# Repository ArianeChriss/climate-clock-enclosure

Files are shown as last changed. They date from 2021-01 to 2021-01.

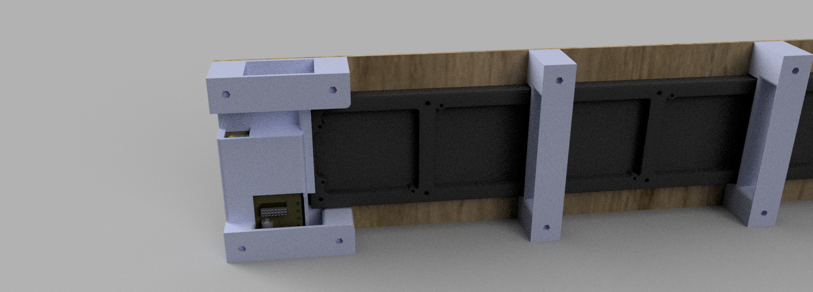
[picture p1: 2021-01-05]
three_panel_enclosure_v3 v19_back.png

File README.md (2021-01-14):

# climate-clock-enclosure
Enclosure design files for the portable versions of the climate clock at https://climateclock.world/make

# Notes:
**The .dxf files need to be updated with slightly smaller holes for the screws, and we're still in the process of testing the printed pieces with heat set inserts instead of nuts. Check back here for updates!!!**

# Materials:
24 M3x8 screws (I use socket cap screws)

24 M3 hex nuts **THIS WILL BE REPLACED WITH HEAT SET INSERTS AS SOON AS THEY ARE TESTED WITH THE DESIGN. AS OF RIGHT NOW, THE TENSION OF SCREWING IN THE WOOD WILL DETACH THE NUTS FROM THE 3D PRINT.**

3d printer filament

2 pieces of 1/8" material for laser cutting, minimum dimensions 27.75"x6" each

# Instructions:
1. Print all .stl files (part modeled in inches, if ridiculously small in print software scale by 2540%)
    center_1.stl
    center_2.stl
    case.stl
    end.stl
2. Laser cut all .dxf files (also designed in inches, dimensions should be 27.75” x 6”)
    front_cut.dxf
    back_cut.dxf
3. Use M3 hex nuts as heat-set inserts, set on top of holes in 3d printed parts, apply soldering iron (set to at least 315℉) and press gently to allow nut to settle into hole
    
    Instructions/description for using heat set inserts at https://markforged.com/resources/blog/heat-set-inserts
4. Center matrix displays on front laser cut piece
5. Place Raspberry Pi and HAT into case, use M3 x 8 screws to attach case, end and center pieces to front laser cut piece
6. May need to snip small plastic tabs off of display molding, depending on which displays are used
7. Attach all power and display cables
8. Use M3 x 8 screws to attach back laser cut piece

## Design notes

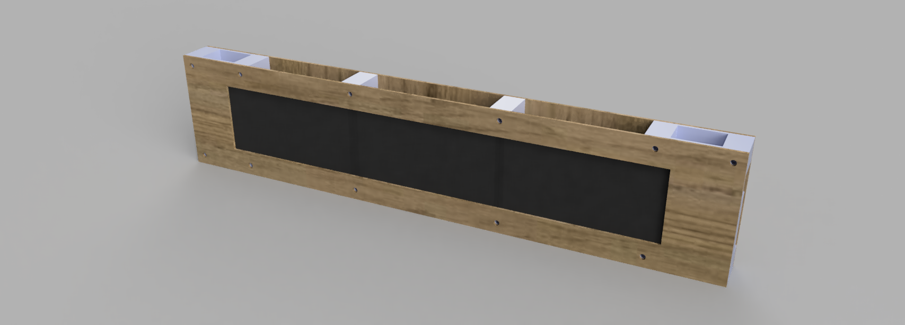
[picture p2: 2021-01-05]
three_panel_enclosure_v3 v19.png

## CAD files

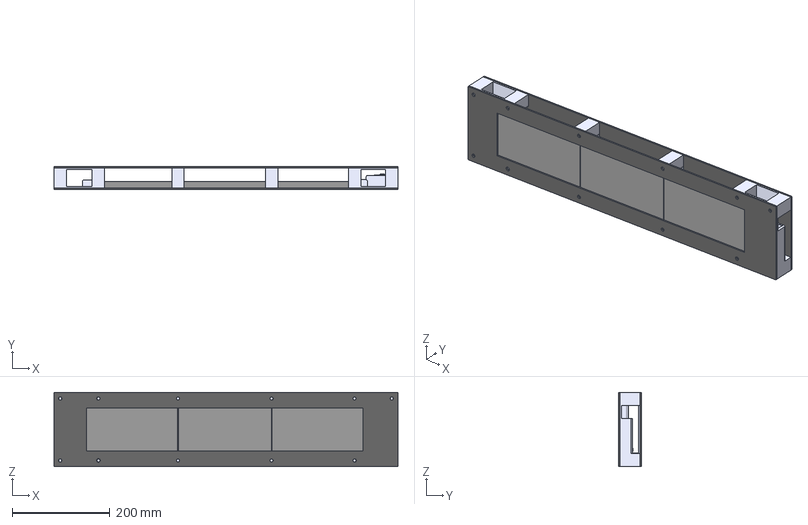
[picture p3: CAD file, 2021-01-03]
three_panel_enclosure_v3 v19.step
704.8 x 47.5 x 152.4 mm
PCB, RPi4ModelB
Gigabit Ethernet Port, RPi4ModelB
hat_component3 v1
3x8 FEMALE
2.1mm DC
frame_front
case
frame_back
panel_1
panel_3
panel_2
end
center_2
center_1

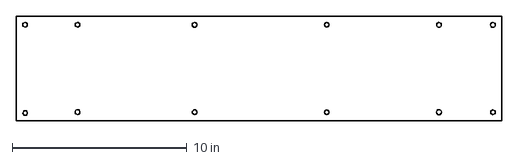
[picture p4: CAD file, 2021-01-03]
back_cut.dxf
27.7 x 6.00 in

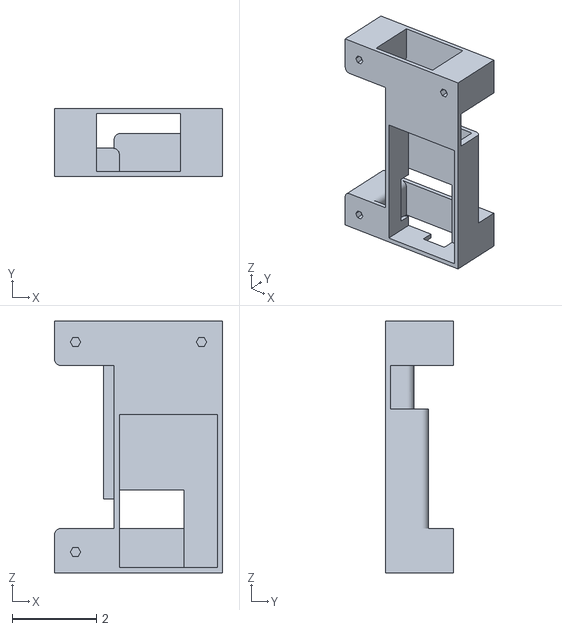
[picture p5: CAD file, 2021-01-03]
case.stl
4.00 x 1.62 x 6.00

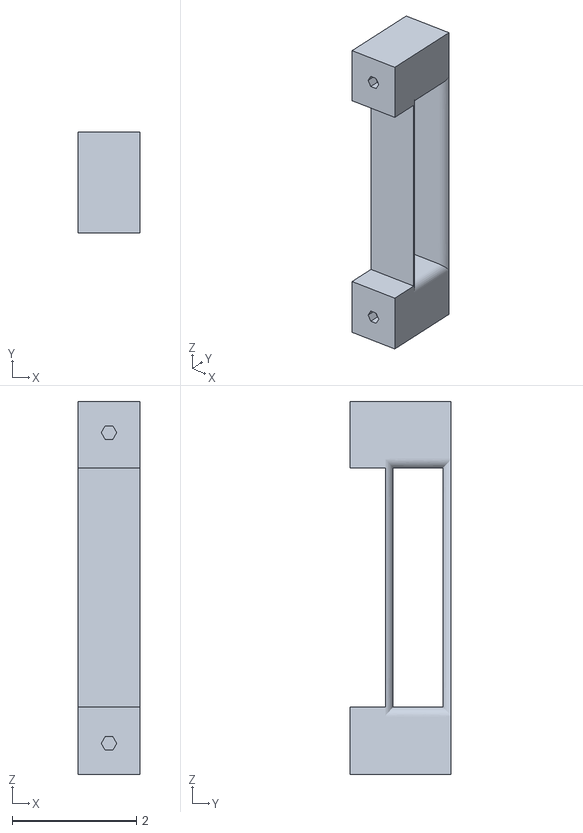
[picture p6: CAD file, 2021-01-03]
center_2.stl
1.00 x 1.62 x 6.00

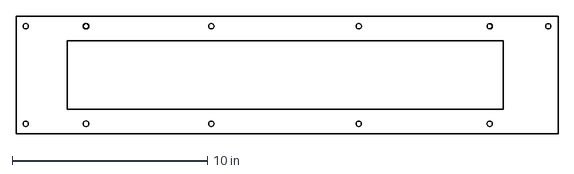
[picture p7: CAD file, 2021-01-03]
front_cut.dxf
27.7 x 6.00 in

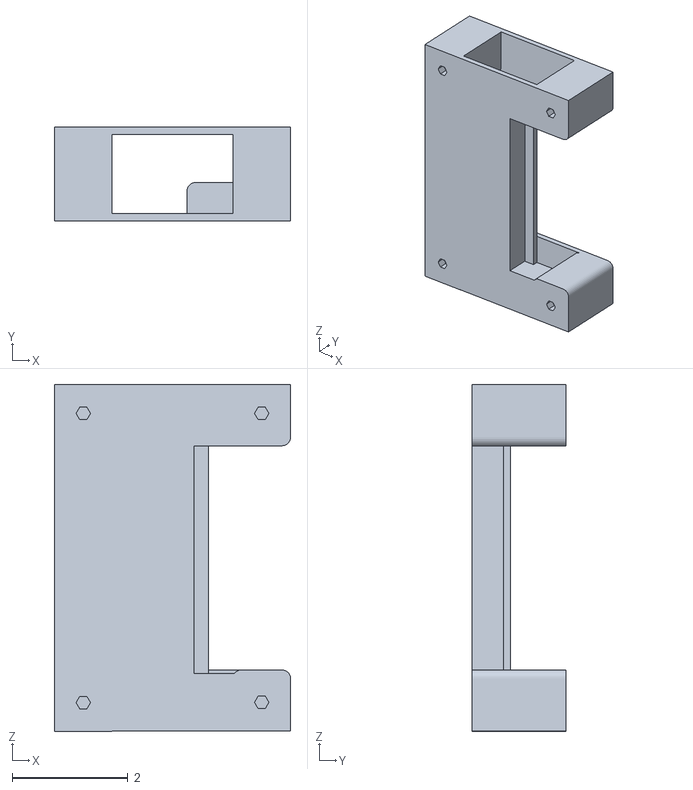
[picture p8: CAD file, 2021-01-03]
end.stl
4.09 x 1.62 x 6.00

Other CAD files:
center_1.stl
